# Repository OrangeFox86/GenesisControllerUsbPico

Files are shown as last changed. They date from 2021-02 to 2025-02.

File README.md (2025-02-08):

# Overview

The code here is meant for the Raspberry Pi Pico microcontroller. It allows for 2 Sega Genesis
controllers to be plugged in and interface with any USB host device.

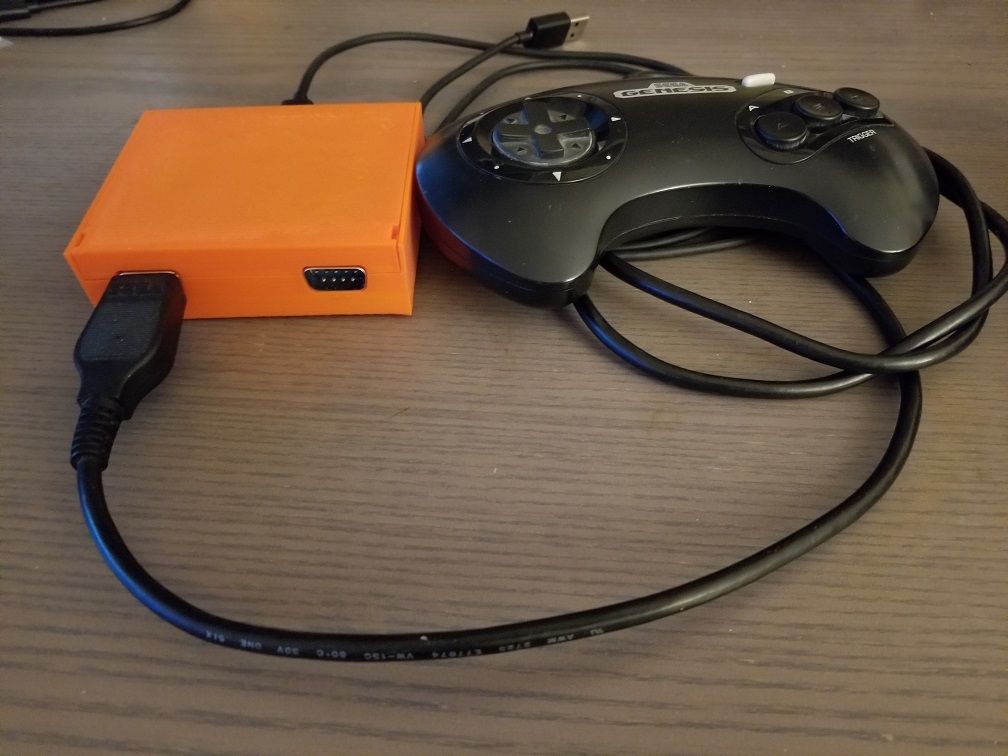
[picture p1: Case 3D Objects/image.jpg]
Final Product 1

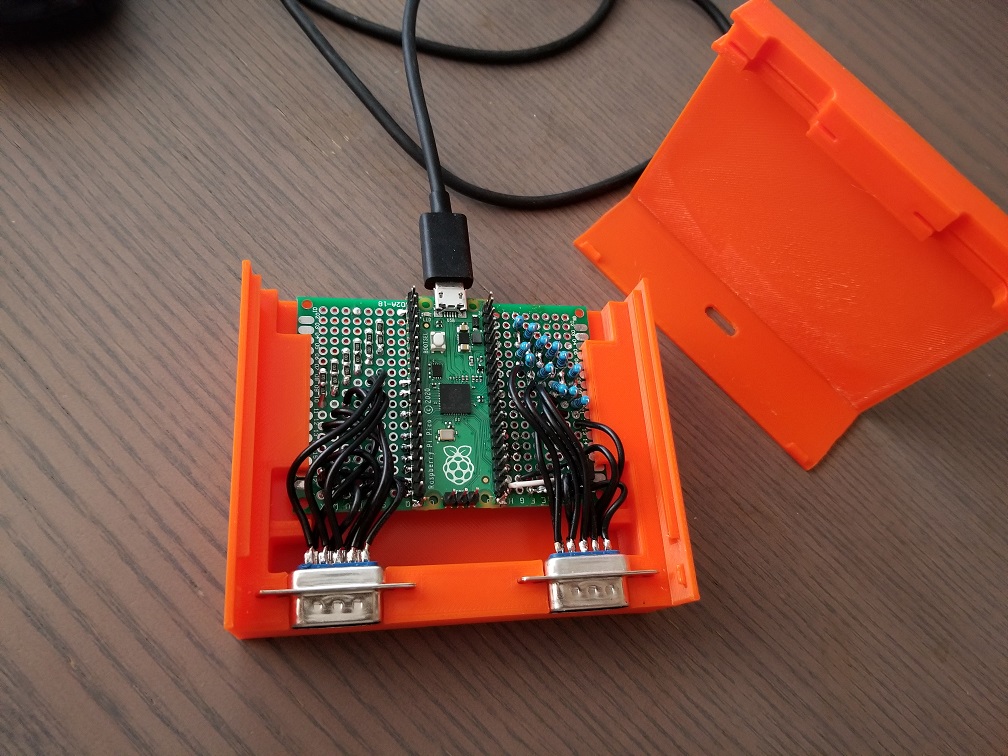
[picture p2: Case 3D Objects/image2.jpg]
Final Product 2


# Hardware

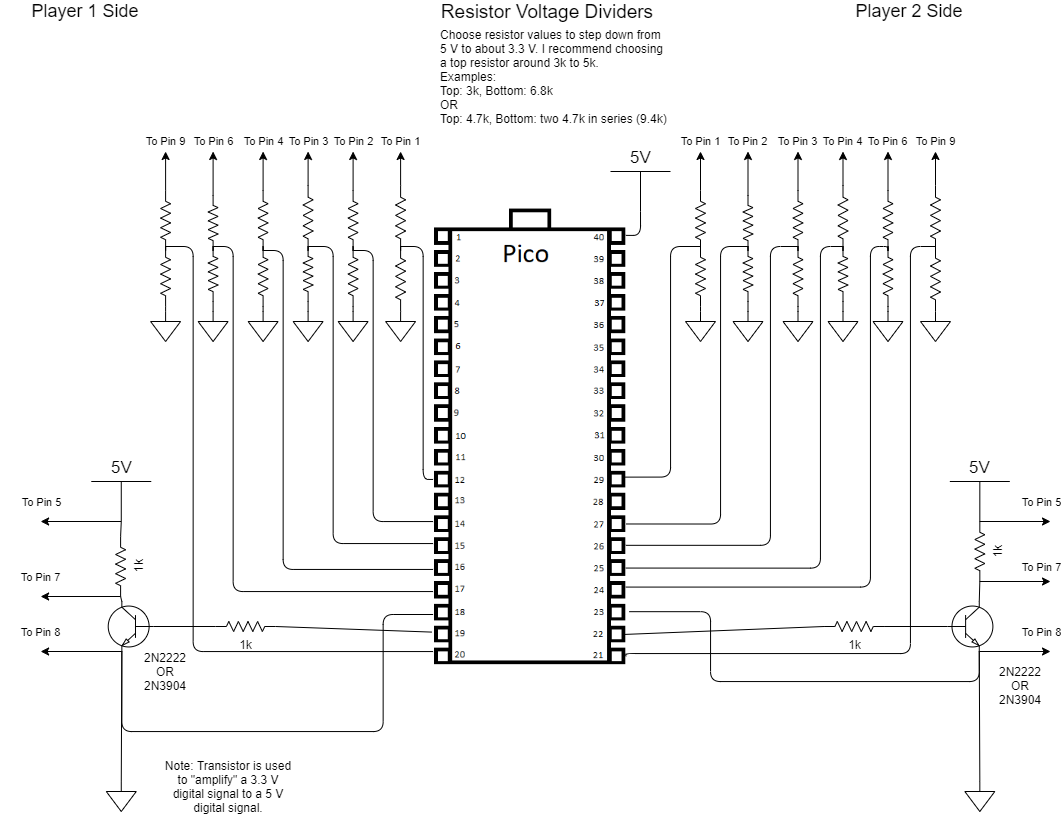
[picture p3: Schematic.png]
Schematic


NOTE: This schematic uses an NPN transistor which inverts the output, so `INVERT_CONTROLLER_OUTPUTS`
in configuration.h is set to `true`. If you decide to use a logic level converter instead, set
`INVERT_CONTROLLER_OUTPUTS` to `false` and recompile.

A standard male DB9 connector may be used for the controller ports.
DB9 Pinout

# Configuration

Refer to configuration.h for settings that may be modified to configure this however you'd like.
Players 1 and 2 may be set as a keyboard or gamepad devices (gamepad by default). Mapped keys may
also be configured there.

When USB_ALWAYS_CONNECTED is true, all controllers are always configured and connected to USB when a
host is present.

When USB_ALWAYS_CONNECTED is set to false, USB will stay disconnected until a controller for player
1 is detected, and then will remain connected until player 1 is removed. The USB descriptor will
automatically update for 1 or 2 players as player 2 is removed or connected. When the USB descriptor
needs to be updated, USB will disconnect for a short while in order to force the update with host.
When player 1 is removed or player 2 is removed while player 1 is connected, the USB interface will
disconnect after the delay of DISCONNECT_DELAY_S. This was all done as a workaround for retropie
purposes to reduce confusion and achieve the following.
- When no controllers are connected, this device will completely detach from USB, forcing retropie
to choose other connected USB or Bluetooth controllers.
- Retropie doesn't do a good job of predictably enumerating 2 controllers under the same USB config.
When there is only a controller connected for player 1, only 1 player will be configured over USB.
If player 2 plugs in, there is still a possibility of the two controllers enumerating incorrectly.
The disconnect delay allows for the user to manually swap controllers without causing
disconnect/reconnect events.

# Build

These instructions assume you're building on a Raspberry Pi.

## Prerequisites

### The SDK

The pico SDK is linked for completeness so that the version that this is compiled and tested with is
documented. You may use your own downloaded version of the SDK without any modifications as long as
your PICO_SDK_PATH environment variable is set.

To use the local copy of the SDK, simply execute `git submodule update --recursive --init`

### CMAKE and Compiler

Ensure cmake and compiler for pico is installed:
`sudo apt install cmake gcc-arm-none-eabi libnewlib-arm-none-eabi build-essential`

### VSCode

Install vscode: `sudo apt install code`

Execute vscode: `cd <project_dir>; code .`

Within vscode, install the extensions `CMake` and `CMake Tools`.

## Compiling the Project

Open the project in code: `cd <project_dir>; code .`

Open the CMake extension in vscode and build GenesisControllerPico. Use gcc-arm-none as your
compiler. If that doesn't show up in the list that pops up, select to search for compatible
compilers, and then try again.

# External Links

Getting started with the Pico SDK:
https://datasheets.raspberrypi.org/pico/getting-started-with-pico.pdf

Youtube video demonstration of this project:
https://www.youtube.com/watch?v=Fbt-3-cg1RE&t=95s

3D printed case on thingiverse (50mm x 70mm dev board and DB9 connectors required):
https://www.thingiverse.com/thing:4761232

Great resources on the Sega Genesis controller:
https://www.raspberryfield.life/2019/03/25/sega-mega-drive-genesis-6-button-xyz-controller/
https://jonthysell.com/2014/07/26/reading-sega-genesis-controllers-with-arduino/

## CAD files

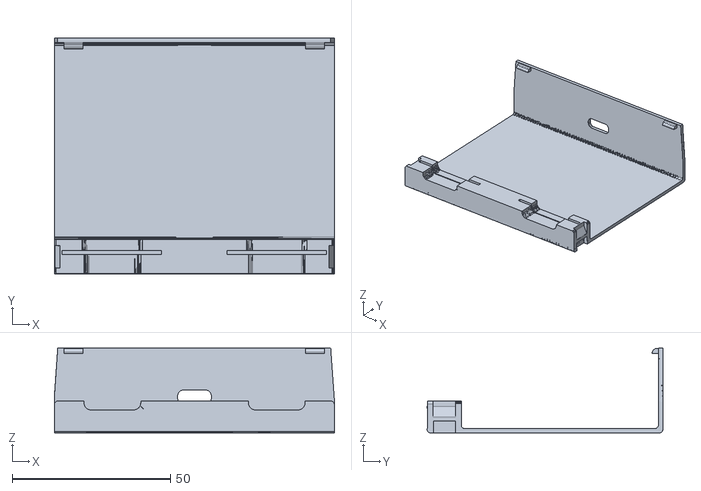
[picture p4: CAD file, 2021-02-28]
Case 3D Objects/Genesis controller to USB case top.stl
88.3 x 74.4 x 26.8

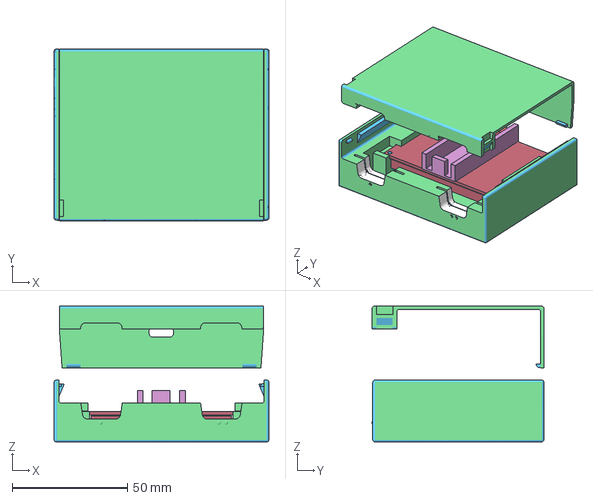
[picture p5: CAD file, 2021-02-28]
Case 3D Objects/Genesis controller to USB case.3mf
93.1 x 74.4 x 58.8 mm

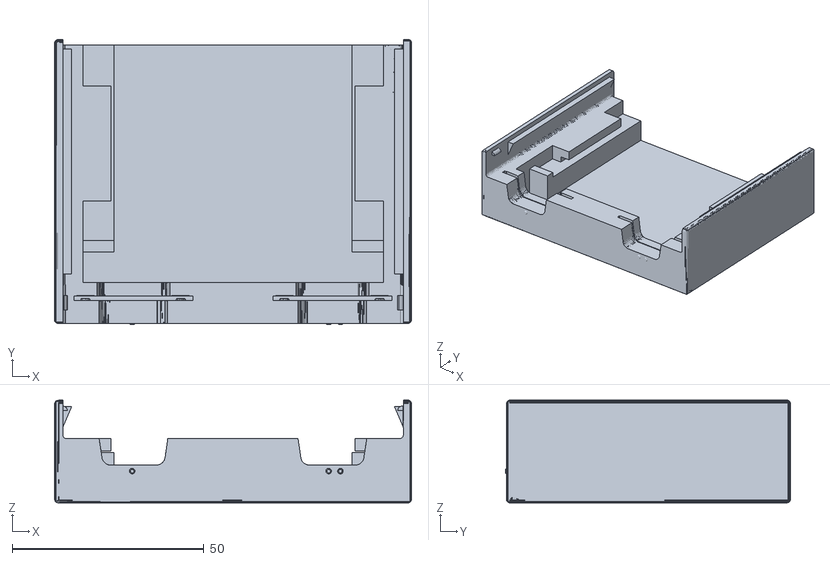
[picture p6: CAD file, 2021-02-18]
Case 3D Objects/Genesis controller to USB case bottom.stl
93.1 x 74.3 x 26.8

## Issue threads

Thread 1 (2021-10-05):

Disconnect delay and manual swapping

Tails86, 2021-10-05:
The purpose of the disconnect delay was to give the user the option to swap player 1 and/or 2 controllers without multiple disconnect/reconnect events. This currently only works if you remove p1 first, remove p2, insert p2, and then insert p1. Deviating from this will cause disconnect/reconnect events.

I propose that the disconnect delay should also apply to player 2 disconnection. The timer should restart on any reconnection. The timer should be shut off if configuration is back to what it was before the first disconnection event.

Version 1.1 has been marked as pre-release until this issue is fixed.

Tails86, 2021-10-05:
fixed

Closed 2021-10-05.

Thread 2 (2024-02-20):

Using a logic level converter instead voltage dividers and transistors

knifesk, 2024-02-20:
TLDR: If you're using a Logic level converter instead of a transistor, set `INVERT_OUTPUTS` in GenesisController.h to `false`;

Hi! firstly, this is more like a contribution than an Issue.

Instead of using a lot of resistors and a transistor I used an 8 channel logic level converter, more specifically the TXS0108E. Mostly because I don't have the right resistors values (nor the required amount) and I already owned the LLC.

I just wired up the same GPIOs on the Pi to the A side and the DB9 pins to the B side of the converter. Wired the 3.3V to VA and the 5v to VB and GND to GND. Also wired a second connection from the 5v to the PIN5 in the DB9.

It was supposed to work right out of the box, but it didn't, well.. most of it worked, but no quite right.. UP, DOWN, Start, A, B and C were working, but not the XYZ and Mode buttons and the LEFT and RIGHT buttons registered as pressed all the time... So I wired everything into my logic analyzer and noticed the problem after digging a couple hours through the code... The Select pin was being pulled LOW when it was supposed to be HIGH and vice-versa. Of course it would, as you're pulling the PIN7 high with a Pull-up resistor and setting the GPIO to HIGH to make the PIN7 go LOW. This was my problem, then I found the "// An NPN is used which inverts the output" comment.. so I set that to false and BOOM! it worked just fine! :D

Thanks for the docs and code, it was really simple to follow up. Well, except the part that I had to compile the entire thing in my very old raspberry pi 2 and it took forever 😅

Cheers!

Tails86, 2024-02-21:
Ah! I'm glad you figured that out. Seems like I should make that more apparent on the README/schematic and maybe move that setting to configuration.h.

Tails86, 2025-02-08:
Sorry it took me a year to get to making this update!

Closed 2025-02-08.

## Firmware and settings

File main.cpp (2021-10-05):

#include <stdlib.h>
#include <stdio.h>
#include <string.h>

#include "bsp/board.h"
#include "pico/stdlib.h"
#include "pico/multicore.h"
#include "UsbKeyboard.h"
#include "UsbGamepad.h"
#include "GenesisController.h"
#include "UsbKeyboardGenesisControllerObserver.h"
#include "UsbGamepadGenesisControllerObserver.h"
#include "timers.h"
#include "usb_descriptors.h"
#include "usb_execution.h"
#include "configuration.h"
#include "device/dcd.h"

// Some error checking
#if (!defined(PLAYER_1_USB_TYPE) \
     || (PLAYER_1_USB_TYPE != USB_TYPE_KEYBOARD && PLAYER_1_USB_TYPE != USB_TYPE_GAMEPAD))
  #error PLAYER_1_USB_TYPE must be defined as USB_TYPE_KEYBOARD or USB_TYPE_GAMEPAD
#endif

#if (!defined(PLAYER_2_USB_TYPE) \
     || (PLAYER_2_USB_TYPE != USB_TYPE_KEYBOARD \
         && PLAYER_2_USB_TYPE != USB_TYPE_GAMEPAD \
         && PLAYER_2_USB_TYPE != USB_TYPE_NONE))
  #error PLAYER_2_USB_TYPE must be defined as USB_TYPE_KEYBOARD, USB_TYPE_GAMEPAD, or USB_TYPE_NONE
#endif

// ****************************
// * Definitions for player 1 *
// ****************************
#if (PLAYER_1_USB_TYPE == USB_TYPE_KEYBOARD)

UsbKeyboard player1UsbDevice(ITF_NUM_HID1, 0);
uint8_t player1KeyMap[IGenesisControllerObserver::KEY_COUNT] = PLAYER1_KEYBOARD_MAPPING;
// The observers send the keys pressed on the controllers to USB keyboards.
// Connecting each controller to its own keyboard allows each controller to independently send up to
// 6 keys.
UsbKeyboardGenesisControllerObserver player1Observer(player1UsbDevice, player1KeyMap);

#elif (PLAYER_1_USB_TYPE == USB_TYPE_GAMEPAD)

UsbGamepad player1UsbDevice(ITF_NUM_HID1, 0);
UsbGamepadGenesisControllerObserver::ButtonMap player1ButtonMap[IGenesisControllerObserver::KEY_COUNT] = GAMEPAD_MAPPING;
UsbGamepadGenesisControllerObserver player1Observer(player1UsbDevice, player1ButtonMap);

#endif

// ****************************
// * Definitions for player 2 *
// ****************************
#if (PLAYER_2_USB_TYPE == USB_TYPE_KEYBOARD)

UsbKeyboard player2UsbDevice(ITF_NUM_HID2, 0);
uint8_t player2KeyMap[IGenesisControllerObserver::KEY_COUNT] = PLAYER2_KEYBOARD_MAPPING;
UsbKeyboardGenesisControllerObserver player2Observer(player2UsbDevice, player2KeyMap);

#elif (PLAYER_2_USB_TYPE == USB_TYPE_GAMEPAD)

UsbGamepad player2UsbDevice(ITF_NUM_HID2, 0);
UsbGamepadGenesisControllerObserver::ButtonMap player2ButtonMap[IGenesisControllerObserver::KEY_COUNT] = GAMEPAD_MAPPING;
UsbGamepadGenesisControllerObserver player2Observer(player2UsbDevice, player2ButtonMap);

#endif

// Consolidation of above objects

UsbControllerDevice* pDevices[NUMBER_OF_DEVICES] =
{
  &player1UsbDevice,
#if (NUMBER_OF_DEVICES > 1)
  &player2UsbDevice
#endif
};

GenesisController gControllers[NUMBER_OF_DEVICES] =
{
  GenesisController(0,
                    GENESIS_CONTROLLER_1_PIN_1,
                    GENESIS_CONTROLLER_1_PIN_2,
                    GENESIS_CONTROLLER_1_PIN_3,
                    GENESIS_CONTROLLER_1_PIN_4,
                    GENESIS_CONTROLLER_1_PIN_6,
                    GENESIS_CONTROLLER_1_PIN_7,
                    GENESIS_CONTROLLER_1_PIN_9,
                    &player1Observer),
#if (NUMBER_OF_DEVICES > 1)
  GenesisController(1,
                    GENESIS_CONTROLLER_2_PIN_1,
                    GENESIS_CONTROLLER_2_PIN_2,
                    GENESIS_CONTROLLER_2_PIN_3,
                    GENESIS_CONTROLLER_2_PIN_4,
                    GENESIS_CONTROLLER_2_PIN_6,
                    GENESIS_CONTROLLER_2_PIN_7,
                    GENESIS_CONTROLLER_2_PIN_9,
                    &player2Observer)
#endif
};

/*------------- MAIN -------------*/
int main(void)
{
  board_init();

  set_usb_devices(pDevices, sizeof(pDevices) / sizeof(pDevices[0]));

  usb_init();

  GenesisController* pController = gControllers;
  for (uint32_t i = sizeof(gControllers) / sizeof(gControllers[0]); i > 0; --i, ++pController)
  {
    pController->pinInit();
  }

  init_timer(gControllers, sizeof(gControllers) / sizeof(gControllers[0]));

  multicore_launch_core1(timer_process);

  while (1)
  {
    usb_task();
  }

  return 0;
}

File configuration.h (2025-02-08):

#ifndef __CONFIGURATION_H__
#define __CONFIGURATION_H__

#include "configuration_constants.h"

// This assumes external pull-down resistor used when false or pull-up when true
#define INVERT_CONTROLLER_INPUTS false

// An NPN is used in normal schematic which inverts the output, so software should invert
#define INVERT_CONTROLLER_OUTPUTS true

// Can be either USB_TYPE_KEYBOARD or USB_TYPE_GAMEPAD
#define PLAYER_1_USB_TYPE     USB_TYPE_GAMEPAD

// Can be USB_TYPE_KEYBOARD, USB_TYPE_GAMEPAD, or USB_TYPE_NONE to disable player 2
#define PLAYER_2_USB_TYPE     USB_TYPE_GAMEPAD

// When true: Forces USB to always be connected for all players
// When false: USB will only connect when player 1 controller is detected and will dynamically
//             update USB descriptor when player 2 is connected/disconnected.
#define USB_ALWAYS_CONNECTED false
// Delay in seconds between controller disconnected and when USB is disconnected or updates.
#define DISCONNECT_DELAY_S 10.0
// Special case delay when only player 1 was connected and disconnects.
#define SINGLE_PLAYER_DISCONNECT_DELAY_S 1.0

// Genesis controller 1 Pico pin definitions
#define GENESIS_CONTROLLER_1_PIN_1 9
#define GENESIS_CONTROLLER_1_PIN_2 10
#define GENESIS_CONTROLLER_1_PIN_3 11
#define GENESIS_CONTROLLER_1_PIN_4 12
#define GENESIS_CONTROLLER_1_PIN_6 13
#define GENESIS_CONTROLLER_1_PIN_7 14
#define GENESIS_CONTROLLER_1_PIN_9 15

// Genesis controller 2 Pico pin definitions
#define GENESIS_CONTROLLER_2_PIN_1 22
#define GENESIS_CONTROLLER_2_PIN_2 21
#define GENESIS_CONTROLLER_2_PIN_3 20
#define GENESIS_CONTROLLER_2_PIN_4 19
#define GENESIS_CONTROLLER_2_PIN_6 18
#define GENESIS_CONTROLLER_2_PIN_7 17
#define GENESIS_CONTROLLER_2_PIN_9 16

#define PLAYER1_KEYBOARD_MAPPING \
{ \
  HID_KEY_RETURN,       /* START */ \
  HID_KEY_W,            /* UP */ \
  HID_KEY_S,            /* DOWN */ \
  HID_KEY_A,            /* LEFT */ \
  HID_KEY_D,            /* RIGHT */ \
  HID_KEY_K,            /* A */ \
  HID_KEY_L,            /* B */ \
  HID_KEY_SEMICOLON,    /* C */ \
  HID_KEY_I,            /* X */ \
  HID_KEY_O,            /* Y */ \
  HID_KEY_P,            /* Z */ \
  HID_KEY_BACKSLASH     /* MODE */ \
}

#define PLAYER2_KEYBOARD_MAPPING \
{ \
  HID_KEY_KEYPAD_ENTER, /* START */ \
  HID_KEY_ARROW_UP,     /* UP */ \
  HID_KEY_ARROW_DOWN,   /* DOWN */ \
  HID_KEY_ARROW_LEFT,   /* LEFT */ \
  HID_KEY_ARROW_RIGHT,  /* RIGHT */ \
  HID_KEY_KEYPAD_1,     /* A */ \
  HID_KEY_KEYPAD_2,     /* B */ \
  HID_KEY_KEYPAD_3,     /* C */ \
  HID_KEY_KEYPAD_4,     /* X */ \
  HID_KEY_KEYPAD_5,     /* Y */ \
  HID_KEY_KEYPAD_6,     /* Z */ \
  HID_KEY_KEYPAD_ADD    /* MODE */ \
}

#if 1
// Configuration specifically for Retropie - If all else fails, this will work with sdl2 driver in
// "fallback configuration" if it can't find a configuration for some reason. If you want XYZ and
// mode buttons to work, make sure you have the setting enabled to use 6 button controller in
// genesis settings (which is usually set to 3 button by default).
#define GAMEPAD_MAPPING \
{ \
  UsbGamepadGenesisControllerObserver::MAP_BUTTON6,      /* START */ \
  UsbGamepadGenesisControllerObserver::MAP_BUTTON11,     /* UP */ \
  UsbGamepadGenesisControllerObserver::MAP_BUTTON12,     /* DOWN */ \
  UsbGamepadGenesisControllerObserver::MAP_BUTTON13,     /* LEFT */ \
  UsbGamepadGenesisControllerObserver::MAP_BUTTON14,     /* RIGHT */ \
  UsbGamepadGenesisControllerObserver::MAP_BUTTON2,      /* A */ \
  UsbGamepadGenesisControllerObserver::MAP_BUTTON0,      /* B */ \
  UsbGamepadGenesisControllerObserver::MAP_BUTTON1,      /* C */ \
  UsbGamepadGenesisControllerObserver::MAP_BUTTON9,      /* X */ \
  UsbGamepadGenesisControllerObserver::MAP_BUTTON3,      /* Y */ \
  UsbGamepadGenesisControllerObserver::MAP_BUTTON10,     /* Z */ \
  UsbGamepadGenesisControllerObserver::MAP_BUTTON4       /* MODE */ \
}
#else
// This is the configuration as recommended by the Tiny USB library
#define GAMEPAD_MAPPING \
{ \
  UsbGamepadGenesisControllerObserver::MAP_BUTTON11,     /* START */ \
  UsbGamepadGenesisControllerObserver::MAP_DPAD_UP,      /* UP */ \
  UsbGamepadGenesisControllerObserver::MAP_DPAD_DOWN,    /* DOWN */ \
  UsbGamepadGenesisControllerObserver::MAP_DPAD_LEFT,    /* LEFT */ \
  UsbGamepadGenesisControllerObserver::MAP_DPAD_RIGHT,   /* RIGHT */ \
  UsbGamepadGenesisControllerObserver::MAP_BUTTON0,      /* A */ \
  UsbGamepadGenesisControllerObserver::MAP_BUTTON1,      /* B */ \
  UsbGamepadGenesisControllerObserver::MAP_BUTTON2,      /* C */ \
  UsbGamepadGenesisControllerObserver::MAP_BUTTON3,      /* X */ \
  UsbGamepadGenesisControllerObserver::MAP_BUTTON4,      /* Y */ \
  UsbGamepadGenesisControllerObserver::MAP_BUTTON5,      /* Z */ \
  UsbGamepadGenesisControllerObserver::MAP_BUTTON12      /* MODE */ \
}
#endif

#endif // __CONFIGURATION_H__

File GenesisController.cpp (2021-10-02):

#include "GenesisController.h"
#include "IGenesisControllerObserver.h"
#include "pico/stdlib.h"
#include <string.h>

GenesisController::GenesisController(uint8_t id,
                                     uint8_t pin1,
                                     uint8_t pin2,
                                     uint8_t pin3,
                                     uint8_t pin4,
                                     uint8_t pin6,
                                     uint8_t pin7,
                                     uint8_t pin9,
                                     IGenesisControllerObserver *pObserver) :
  id(id),
  inputPins{pin1, pin2, pin3, pin4, pin6, pin9},
  inputMasks{1UL << pin1, 1UL << pin2, 1UL << pin3, 1UL << pin4, 1UL << pin6, 1UL << pin9},
  allInputsMask(1UL << pin1 | 1UL << pin2 | 1UL << pin3 | 1UL << pin4 | 1UL << pin6 | 1UL << pin9),
  selectPin(pin7),
  allOutputsMask(1 << pin7),
  controllerState(STATE_DISCONNECTED),
  pObserver(pObserver),
  keyStatus(),
  controllerSensed(false),
  connectingCount(0)
{}

void GenesisController::pinInit()
{
  // Initialize all GPIO
  uint32_t allGpioMask = allInputsMask | allOutputsMask;
  gpio_init_mask(allGpioMask);
  gpio_set_dir_masked(allGpioMask, allOutputsMask);
  // Set all inputs as pull down
  const uint8_t* pPin = inputPins;
  for (uint32_t i = INPUT_PIN_COUNT; i > 0; --i, ++pPin)
  {
    // Assume external pull resistors
    gpio_disable_pulls(*pPin);
  }
  setSelect(true); // Initial select is HIGH
}

void GenesisController::nextSignal(uint8_t count, uint32_t inputs)
{
  if (controllerState == STATE_CONNECT_INIT || controllerState == STATE_CONNECTED)
  {
    // LOW at count 0 and even number counts
    // HIGH on odd number counts
    setSelect((count & 1) != 0);
  }
  else
  {
    // Keep select HIGH until controller is sensed
    setSelect(true);
  }
  // Saved input is for the previously set select state
  // Inputs for count 0 means the state while idle HIGH
  savedInputs[count] = inputs;
  if (count == NUM_COUNTS - 1)
  {
    // Reached the max count; time to process all of the saved inputs
    processSignals();
  }
}

void GenesisController::commitSignals()
{
  if (pObserver != nullptr)
  {
    // Time to commit all key changes
    pObserver->send();
  }
}

void GenesisController::checkConnection()
{
  bool lastState = controllerSensed;
  // Sensed when anything is HIGH when not inverted (assumes pull-down is used)
  // Or when anything is LOW when inverted (assumes pull-up is used)
  controllerSensed = (savedInputs[0] & allInputsMask) != (INVERT_INPUTS ? allInputsMask : 0);
  if (lastState != controllerSensed)
  {
    if (controllerSensed)
    {
      controllerConnected();
    }
    else
    {
      controllerDisconnected();
    }
  }
}

void GenesisController::controllerConnected()
{
  if (pObserver != nullptr)
  {
    pObserver->controllerConnected(id);
  }
  controllerState = STATE_CONNECTING;
  memset(keyStatus, 0, sizeof(keyStatus));
  isSixButton = false;
  connectingCount = 0;
}

void GenesisController::controllerDisconnected()
{
  if (pObserver != nullptr)
  {
    pObserver->controllerDisconnected(id);
  }
  controllerState = STATE_DISCONNECTED;
  memset(keyStatus, 0, sizeof(keyStatus));
  isSixButton = false;
  connectingCount = 0;
}

void GenesisController::updateKey(IGenesisControllerObserver::Key key, bool state)
{
  if (INVERT_INPUTS)
  {
    state = !state;
  }
  if (keyStatus[key] != state)
  {
    keyStatus[key] = state;
    if (pObserver != nullptr)
    {
      pObserver->keyStateChanged(id, key, state);
    }
  }
}

void GenesisController::processSignals()
{
  checkConnection();

  switch (controllerState)
  {
    default: // Fall through
    case STATE_DISCONNECTED:
      // Nothing further to do
      break;

    case STATE_CONNECTING:
    {
      // Stay at connecting state until MAX_CONNECTING_COUNT has been reached */
      if (++connectingCount >= MAX_CONNECTING_COUNT)
      {
        connectingCount = 0;
        controllerState = STATE_CONNECT_INIT;
      }
    }
    break;

    case STATE_CONNECT_INIT:
    {
			// Purpose of this state is to figure out what kind of controller we have (3 or 6 button).
      isSixButton = getInput(7, INPUT_PIN_RI_MO);
      controllerState = STATE_CONNECTED;
    }
    break;

    case STATE_CONNECTED:
    {
      // Get next button state
      updateKey(IGenesisControllerObserver::KEY_A, !getInput(3, INPUT_PIN_A_B));
      updateKey(IGenesisControllerObserver::KEY_START, !getInput(3, INPUT_PIN_ST_C));
      updateKey(IGenesisControllerObserver::KEY_UP, !getInput(2, INPUT_PIN_UP_Z));
      updateKey(IGenesisControllerObserver::KEY_DOWN, !getInput(2, INPUT_PIN_DN_Y));
      updateKey(IGenesisControllerObserver::KEY_LEFT, !getInput(2, INPUT_PIN_LE_X));
      updateKey(IGenesisControllerObserver::KEY_RIGHT, !getInput(2, INPUT_PIN_RI_MO));
      updateKey(IGenesisControllerObserver::KEY_B, !getInput(2, INPUT_PIN_A_B));
      updateKey(IGenesisControllerObserver::KEY_C, !getInput(2, INPUT_PIN_ST_C));
      if (isSixButton)
      {
        updateKey(IGenesisControllerObserver::KEY_Z, !getInput(6, INPUT_PIN_UP_Z));
        updateKey(IGenesisControllerObserver::KEY_Y, !getInput(6, INPUT_PIN_DN_Y));
        updateKey(IGenesisControllerObserver::KEY_X, !getInput(6, INPUT_PIN_LE_X));
        updateKey(IGenesisControllerObserver::KEY_MODE, !getInput(6, INPUT_PIN_RI_MO));
      }
    }
    break;
  }
}

bool GenesisController::getInput(uint8_t count, InputPinSelect pin)
{
  bool input = ((inputMasks[pin] & savedInputs[count]) != 0);
  if (INVERT_INPUTS)
  {
    input = !input;
  }
  return input;
}

void GenesisController::setSelect(bool state)
{
  gpio_put(selectPin, INVERT_OUTPUTS ? !state : state);
}

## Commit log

2021-02-13 Added simple schematic
2021-02-14 Reduced schematic size to fit on one page
2021-02-15 Added case 3D objects to project
    [Genesis controller to USB case bottom.stl, Genesis controller to USB case top.stl, Genesis controller to USB case.3mf]
2021-02-17 Updated 3D objects
    put a radius on most edges and made top DB9 slots deeper
    [Genesis controller to USB case bottom.stl, Genesis controller to USB case top.stl, Genesis controller to USB case.3mf]
2021-02-18 Update Genesis controller to USB case top.stl
    Taper the lid just a bit
    [Genesis controller to USB case top.stl]
2021-02-18 Update Genesis controller to USB case.3mf
    [Genesis controller to USB case.3mf]
2021-02-18 Updated 3D objects
    Rounded some more corners
    [Genesis controller to USB case bottom.stl, Genesis controller to USB case top.stl, Genesis controller to USB case.3mf]
2021-02-28 Tweaked case top object
    [Genesis controller to USB case top.stl, Genesis controller to USB case.3mf]
2021-09-26 Updated for new tinyusb updates; added gamepad option and switched default to gamepad (cleanup still needed)
2021-09-27 Moved configurable items to configuration.h
    [configuration.h]
2021-09-27 Renamed 'UsbController' to 'UsbGamepad' to avoid confusion
    [configuration.h]
2021-09-29 Fixed dpad setup for UsbGamepad; made gamepad button selection configurable in configuration.h
    [configuration.h]
2021-09-29 Corrected pin numbers in configuration
    [configuration.h]
2021-10-01 Can now configure USB device type for player 1 and 2 separately
    [configuration.h]
2021-10-02 Put devices on different interfaces
    [configuration.h]
2021-10-02 Updated gamepad button configuration to something known to work on retropie; keep USB disconnected until at least 1 controller is detected
    [configuration.h]
2021-10-02 Bug fixes and improvements
    [configuration.h]
2021-10-03 - Added the pico sdk that was used to build this project- Removed the build directory in favor of making a formal release- Added gitignore file to ignore the build directory
2021-10-05 - Wait 10 seconds before disconnecting once player 1 is removed- Updated makefile to choos local pico sdk only if it has been pulled- Put more information into and reorganized the readme
    [configuration.h]
2021-10-05 - Added a special case for disconnect delay when only player 1 is connected (default 1 second)- Updated player 1 / player 2 configuration macros to limit total number of macros
    [configuration.h, configuration_constants.h]
2021-10-05 Don't recommend to install C/C++ extension in vscode - it runs real slowly on raspberry pi when you change configuration macros
2021-10-09 Update README.md
    Added note that build instructions assume Raspberry Pi env
2025-02-08 2: Moved inversion booleans to configuration so their more visible and added note so it's very clear that the design on the readme inverts outputs
    [configuration.h]
